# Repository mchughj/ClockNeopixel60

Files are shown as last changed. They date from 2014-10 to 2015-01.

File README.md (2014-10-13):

ClockNeopixel60
===============

An Arduino (ATTiny85 and ATmega328) clock project that uses a 60 neopixel ring.

This is the 60 pixel neopixel clock program written by Jason McHugh.  Feel free to drop me a line at mchughj@gmail.com for questions, comments, criticisms, concerns, etc.  :)  I've included here the sketches used as well as a Fritzing circuit diagram (both .fzz and .png forms).

The backstory.

I originally bought a 16 pixel neopixel ring, a trinket, and an RTC module:

- Trinket:        https://www.adafruit.com/product/1501
- 16 pixel ring:  https://www.adafruit.com/product/1463
- RTC DS1307:     https://www.adafruit.com/product/264

I used the 16 pixel ring in another project for my son Aidan (who went camping with his 6th grade class, so I created a 2 way mirror with the ring behind the mirror).  I saw the 60 pixel ring and decided to get one (well, actually 4):

- 60 pixel ring:  https://www.adafruit.com/product/1768

Squeezing a nicely animating LED clock into the 5,310 byte maximum of the trinket wasn't easy.  Just using the TimeWireM and TinyRTClib libraries used up 3,146 bytes of space.  This left just ~ 2k of space to do something neat.  I'm sure if I were writing the assembly and really thinking hard about how to do this then it wouldn't be too challenging.  But writing 'regular' C code made it non-trivial.  

I could have moved to an Arduino and not had to worry about the space but I wanted to challenge myself a bit and fit it on the ATTiny85.  

I wrote the follow after observing clocks and thinking about what I thought the ideal animation/behavior would be.

I use this program in two separate scenarios.  

1/  The first is using an 8mhz Trinket with a physical RTC module attached to it.  This was my final intended configuration but it left very little space for debugging problems.  

In this first mode you have to have installed the TinyWireM and TinyRTClib installed. 

- https://github.com/adafruit/TinyWireM
- https://github.com/adafruit/TinyRTCLib

2/  The second scenario in which this program can be used is using a bare Arduino.  No RTC is required in this configuration - the millis implementation is used.  This mode allowed me to debug lots of problems with my original implementation so you will see lots of Serial debugging output and the ability to set a specific time.  In this second mode you have to have installed the RTClib.
  https://github.com/adafruit/RTClib

These two modes of operation are just the specific builds that I have.  There is nothing magical about them and additional configurations can be achieved by changing the code below.  

To set the two modes you have to do two things:

1/  In the Arduino programming environment select either 'Uno' or 'Adafruit Trinket 8mhz'.  Based on this setting everything else should be derived.   (Remember to set the programmer to be "USBTinyISP" if you are using the trinket!   If  you see lots of errors with "not in sync" then this can be why.)

2/  Uncomment or comment out the Wire.h, RTClib.h, TinyWireM, and TinyRTClib.  This shouldn't be necessary but apparently the Arduino programming environment uses a simple scan of all #includes in order to know what libraries might be used.  The preprocessor and directives are not used which makes this, IMO, a bug.  So the workaround is to comment and uncomment.

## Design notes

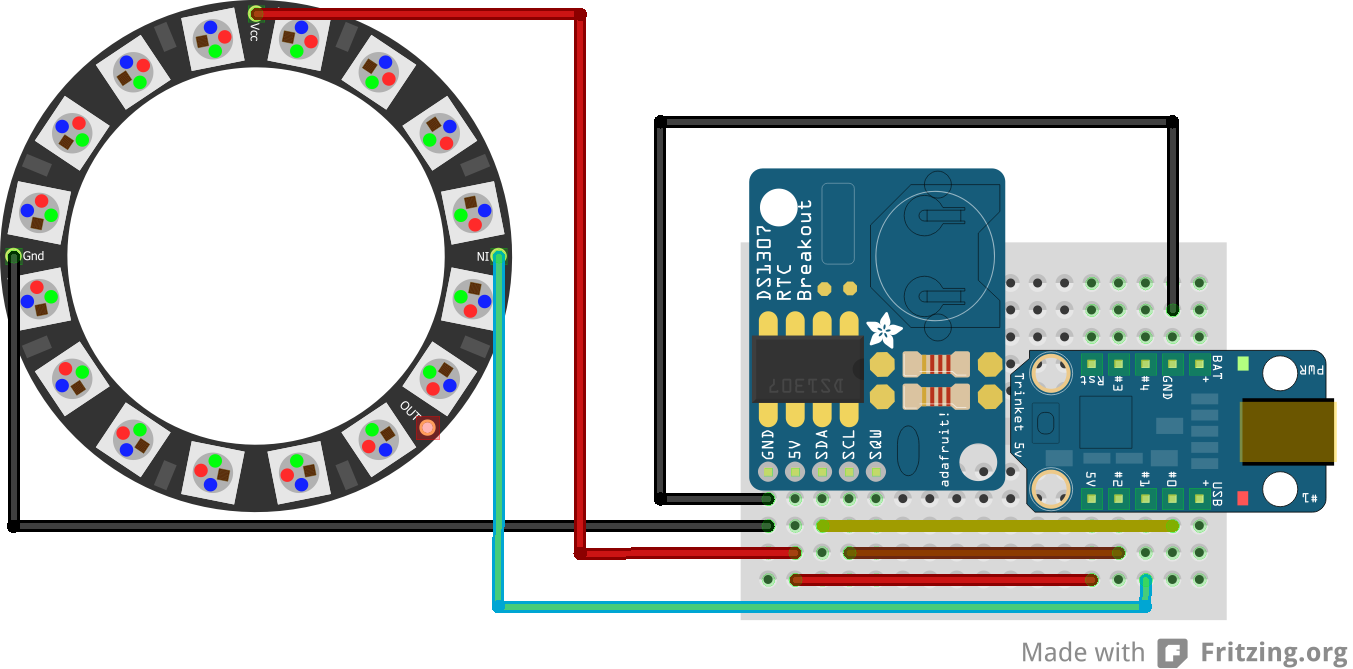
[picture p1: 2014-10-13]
Pixel-Ring-Trinket-Clock.png

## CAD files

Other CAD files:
Mom/DS1307AndArduinoProHolders.skp
Mom/ElectronicsEnclosure.skp

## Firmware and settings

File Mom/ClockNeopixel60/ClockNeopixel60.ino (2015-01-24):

/**
 * This is the 60 pixel neopixel clock program written by Jason McHugh.
 * 
 * This is a copy of my original program that I've forked and extended.  
 * In December 2014 my mother came to visit and remarked, several times!, 
 * how much she liked my clock.  I decided, with the prompting of a very
 * good friend, to make one for her.
 *
 * In making this version I decided to be smart this time in two 
 * significant ways.
 *
 * 1/  In the original version I challenged myself by putting the program
 * on a trinket - which has very limited memory space.  After putting on the
 * TinyWireM and TinyRTClib libraries I had only 3,146 bytes of programmer
 * space.  This time I'm using an Arduino Pro Mini with a full 8k of space.
 * This is huge and really makes the entire project easier.
 *
 * 2/  Day light savings time wasn't handled in my prior project so I'm adding
 * two buttons to support moving the hour and the minutes.  Minutes shouldn't 
 * be necessary but in case they want to synchronize with other clocks in the
 * house.
 * 
 * Project contents:
 *
 *   60 pixel ring:    https://www.adafruit.com/product/1768
 *   Arduino Pro Mini: https://www.sparkfun.com/products/11113
 *   RTC DS1307:       https://www.adafruit.com/product/264
 *   Pushbuttons:      https://www.adafruit.com/products/1009
 * 
 * End results: 
 * 
 *   1/  Interrupt service routines for buttons
 *   2/  Nicely animated clocks
 *   3/  Super happy Mom
 *
 * If you are interested in seeing a build of this project that works under
 * different settings then look around for the original Neopixel 60 clock
 * project.
 *
 * This project requires:
 *
 *   https://github.com/adafruit/RTClib
 *   https://github.com/adafruit/Adafruit_NeoPixel
 *
*/

// Use the serial libraries for debugging
#include <Serial>
#include <Wire.h>
#include <RTClib.h>
#define PIN 5

#include <Adafruit_NeoPixel.h>

// Uncomment out the following line to set the time.  Remember
// to reflash the same program with this commented out so that subsequent
// restarts don't reset the time.
// #define SET_TIME

// Uncomment out the following, but only when SET_TIME is defined,
// in order to test specific time values.
// #define USE_MANUAL_TEST_TIME

// Neopixel pin for the lights
#define NUMBER_PIXELS 60
#define BRIGHTNESS 128 // set max brightness

#define START_VALUE 0xfe

uint8_t hourTriggered = 0;
uint8_t minuteTriggered = 0;
uint32_t triggerTime;
uint8_t hourOffset = 0;
uint8_t minuteOffset = 0;

RTC_DS1307 rtc; // Clock object uses the real time clock module

Adafruit_NeoPixel strip = Adafruit_NeoPixel(NUMBER_PIXELS, PIN, NEO_GRB + NEO_KHZ800); // strip object

byte priorHourPixel = START_VALUE;
byte priorMinuteVal = START_VALUE;
byte priorSecondVal = START_VALUE;
boolean shownFifteen = false;

void setUniformRingColor( uint32_t color) {
    for(uint16_t i=0; i<NUMBER_PIXELS; i++) {
        strip.setPixelColor(i, color );
    }
}

void showOrientation() {
  Serial.println( "Going to show orientation" );
  setUniformRingColor(0);
  int numLeds = NUMBER_PIXELS;

  Serial.println( F("Top (Red): 0") );
  Serial.print( F("Right (Green): " ));
  Serial.println( (int) numLeds/4 );
  Serial.print( F("Bottom (Blue): " ));
  Serial.println( (int) numLeds/2 );
  Serial.print( F("Left (White): " ) );
  Serial.println( (int) numLeds/4*3 );
  
  for( int i = 0; i < 10; i++ ) {
      strip.setPixelColor(0, 0xff0000);
      strip.setPixelColor(numLeds/4, 0x00ff00);
      strip.setPixelColor(numLeds/2, 0x0000ff);
      strip.setPixelColor(numLeds/4*3, 0xffffff);
      strip.show();
      delay(150);
      setUniformRingColor(0);
      strip.show();
      delay(150);
  }
}

void setup () {
  strip.begin();
  strip.setBrightness(BRIGHTNESS); // set brightness
  
  Wire.begin();
  rtc.begin();

  Serial.begin(9600);
  Serial.println( F("Running Neopixel Clock 60 with serial debugging" ));
  Serial.print( F("Date: " ));
  Serial.print( __DATE__ );
  Serial.print( F(", Time: ") );
  Serial.println( __TIME__ );
  Serial.print( F("Initializing light pin to " ));
  Serial.println( PIN );
  showOrientation();

  if (! rtc.isrunning()) {
    Serial.println("RTC is NOT running!");
  }
   
#ifdef SET_TIME 
#ifdef USE_MANUAL_TEST_TIME
  const char *date = "Oct 12 2014";
  const char *time = "13:59:52";
#else
  const char *date = __DATE__;
  const char *time = __TIME__;;
#endif
 
  Serial.print( F("Going to manually set the RTC time to: "));
  Serial.print( date );
  Serial.print( F(" " ));
  Serial.println( time );
  rtc.adjust(DateTime( date, time ) );
#endif

  while(! rtc.isrunning()) {
    Serial.println("RTC is NOT running!");
  }
  
  // Enable interrupt 0 (pin 2) which is connected to a button
  // that controls the hour increment.
  attachInterrupt(0, incrementHour, RISING);

  // Enable interrupt 1 (pin 3) which is connected to a button
  // that controls the minute increment.
  attachInterrupt(1, incrementMinute, RISING);
}


/**
 * This routine will add a red, green, and blue color value to the current
 * color value for a pixel.  This creates a blend of the two colors. 
 *
 * The specific index for the pixel to be set can have a value -NUMBER_PIXELS
 * to NUMBER_PIXELS and it will be normalized into the range of 0 ->
 * NUMBER_PIXELS - 1.
 */
void addColorToPixel( int pixel, int red, int green, int blue ) { 
   if( pixel == NUMBER_PIXELS ) { 
     pixel = 0;
   } else if ( pixel < 0 ) { 
     pixel = NUMBER_PIXELS + pixel;
   }
   uint32_t currentPixelColor = strip.getPixelColor(pixel);
   
   int currentRed = (currentPixelColor & 0xFF0000) >> 16;
   int currentGreen = (currentPixelColor & 0x00FF00) >> 8;
   int currentBlue = currentPixelColor & 0x0000FF;
   
   strip.setPixelColor(pixel, currentRed + red, currentGreen + green, currentBlue + blue);
}

/**
 * Adds a color to a pixel, via addColorToPixel, and then does the same for
 * the surrounding pixels but at a reduced intensity.
 */
void addColorToPixelAndShadeAround( int pixel, uint8_t red, uint8_t green, uint8_t blue ) { 
    addColorToPixel( pixel, red, green, blue);
    red = red >> 4;
    green = green >> 4;
    blue = blue >> 4;
    
    addColorToPixel(pixel+1,red,green,blue);
    addColorToPixel(pixel-1,red,green,blue);
}

/**
 * Draw a single frame of a transition.  
 *
 * This method takes in the pixel that it will be animating, what the current
 * step of the animation is, the maximum number of steps, and finally the
 * color for the central pixel.  
 *
 * The animation frame will 'bleed' the color from the initial three pixels
 * into four pixels - the original three and the next pixel.
 */
void showTransitionStep( int pixel, int curTransitionStep, int maxTransitionSteps, int red, int green, int blue ) { 

   // The pixel that we are leaving
   addColorToPixel( pixel - 2, 
       red >> (4+curTransitionStep), 
       green >> (4+curTransitionStep), 
       blue >> (4+curTransitionStep) );

   // The pixel that used to be the brightest but now will be shaded dimly and
   // which preceeds the actual pixel for the time.
   addColorToPixel( pixel - 1, red >> curTransitionStep, green >> curTransitionStep, blue >> curTransitionStep );

   // The pixel that will now be the brightest and center.
   addColorToPixel( pixel, red >> (4-curTransitionStep), green >> (4-curTransitionStep), blue >> (4-curTransitionStep) );

   // Finally the pixel that follows the brightest which will become shaded
   // and bright as the transition nears the max steps.
   addColorToPixel( pixel+1, 
       red >> ( 4 + maxTransitionSteps - curTransitionStep), 
       green >> ( 4 + maxTransitionSteps - curTransitionStep), 
       blue >> ( 4 + maxTransitionSteps - curTransitionStep) );
}


/**
 * Show the transition from one time to the next.
 */
void transition( int hourVal, byte minuteVal, byte secondVal ) { 
  uint8_t amount = 0xff;
  int time = 200;
  int maximumTransitions = 4;
  int hourPixel = map( hourVal, 0, 719, 0, 59 );

  for( int i = 0; i <= maximumTransitions; i++ ) { 
       setUniformRingColor(0);
       
       if( priorHourPixel != hourPixel ) { 
         showTransitionStep( hourPixel, i, maximumTransitions, 0xff, 0, 0 );
       } else {
         addColorToPixelAndShadeAround( hourPixel, 0xff, 0, 0 );
       }
       
       if( priorMinuteVal != minuteVal ) { 
         showTransitionStep( minuteVal, i, maximumTransitions, 0, 0xff, 0 );
       } else {
         addColorToPixelAndShadeAround( minuteVal, 0, 0xff, 0 );
       }
       showTransitionStep( secondVal, i, maximumTransitions, 0, 0, 0xff);
       
       strip.show();
       delay(time);
  }
  priorHourPixel = hourPixel;
}

uint32_t Wheel(byte WheelPos) {
  if(WheelPos < 85) {
   return strip.Color(WheelPos * 3, 255 - WheelPos * 3, 0);
  } else if(WheelPos < 170) {
   WheelPos -= 85;
   return strip.Color(255 - WheelPos * 3, 0, WheelPos * 3);
  } else {
   WheelPos -= 170;
   return strip.Color(0, WheelPos * 3, 255 - WheelPos * 3);
  }
}

void showColorWheel() {
  uint16_t i, j;

  // Turn down the brightness to be safe.  There are 60 pixels and at full brightness and with
  // all white then each would be about 60 milliamps.  This is 3.6 amps total.  I'm using a 2
  // amp power supply.  I've set the default BRIGHTNESS to be a safe value even with all white
  // but here I'm going to decrease it just a bit to be extra safe.
  strip.setBrightness(BRIGHTNESS*0.85);
  for(j=256*4; j>0; j--) { 
    for(i=0; i< strip.numPixels(); i++) {
      strip.setPixelColor(i, Wheel(((i * 256 / strip.numPixels()) + j) & 255));
    }
    strip.show();
    delay(3);
  }
  strip.setBrightness(BRIGHTNESS);
}

void showFifteenMinuteIncrements(byte minuteVal) {
  uint32_t color;
  if( minuteVal == 0 ) { 
    
    showColorWheel();
    return;
  } else if( minuteVal == 15 ) { 
    color = 0x00ff00;
  } else if( minuteVal == 30 ) { 
    color = 0xff0000;
  } else if( minuteVal == 45 ) { 
    color = 0x0000ff;
  } else {
    color = 0xff00ff;
  }
  for( int i = 0; i < 5; i++ ) { 
        setUniformRingColor( color );
        strip.show();
        delay(300);
        setUniformRingColor( 0x0 );
        strip.show();
        delay(300);
    }
}

void loop() 
{
  uint32_t currentTime = millis();
  
  // Look to see if the interrupt routines registered a button press.  
  // If so then acknowledge the trigger and, if it is the first pass
  // through this main loop since it has been triggered, run the routine
  // to process the button press.
  if( hourTriggered == 1 ) { 
    hourTriggered = 0;
    Serial.println( "Hour triggered" );
    if (triggerTime == 0) {
      Serial.println( "Incrementing hour offset" );
      triggerTime = currentTime;
      incrementHourOffset();
    }
  }
  if( minuteTriggered == 1 ) { 
    minuteTriggered = 0;
    Serial.println( "Minute triggered" );
    if (triggerTime == 0) {
      Serial.println( "Incrementing minute" );
      triggerTime = currentTime;
      incrementMinuteOffset();
    }
  }
  
  // Handle a uint32_t wrapping around every couple of days or so.
  if( triggerTime + 750 < triggerTime ) { 
    triggerTime = 0;
  }  
  
  // After some amount of times has passed allow another trigger event to occur.
  if( triggerTime != 0 && currentTime > triggerTime + 750 ) { 
    triggerTime = 0;
  }
  
  // Get the current time
  DateTime n = rtc.now(); 

  byte secondVal = n.second();  
  byte minuteVal = n.minute();  
 
  // Since hour granularity is too coarse - we have 60 pixels and there are
  // only 12 hour values - we translate the raw hour value into an hourVal
  // which is the number of minutes that have elapsed within the 12 hour
  // period.  This gives us a range from 0 to 719 which can be mapped to the
  // ring's 60 pixels nicely.
  byte hour = n.hour();
  hour += hourOffset;
  while( hour >= 12 ) { 
    hour -= 12;
  }
  
  minuteVal += minuteOffset;
  if( minuteVal > 60 ) { 
    minuteVal -= 60;
  }
  
  uint16_t hourVal = ((uint16_t)hour) * 60 + ( uint16_t) minuteVal;
  
  Serial.print( "currentHour: " );
  Serial.print( hour );
  Serial.print( ", hourVal: " );
  Serial.print( hourVal );
  Serial.print( ", currentMinute: " );
  Serial.print( minuteVal );
  Serial.print( ", currentSecond: " );
  Serial.println( secondVal );
  
  if( priorSecondVal == secondVal ) { 
      return;
  }   
  
  transition( hourVal, minuteVal, secondVal );
  
  priorMinuteVal = minuteVal;
  priorSecondVal = secondVal;

  // Every fifteen minutes do a little something obvious to indicate that
  // time has passed.
  if(( minuteVal == 0 || minuteVal == 15 || minuteVal == 30 || minuteVal == 45 ) ) {
    if( shownFifteen == false ) { 
       showFifteenMinuteIncrements( minuteVal );
       shownFifteen = true;
    }
  } else { 
    shownFifteen = false;
  }
}

// ISR for hour button
void incrementHour() {
  hourTriggered = 1;
}

void incrementHourOffset() {
    hourOffset++;
    if( hourOffset == 24 ) { 
       hourOffset = 0;
    }
}


// ISR for minute button
void incrementMinute() {
  minuteTriggered = 1;
}

void incrementMinuteOffset() {
    minuteOffset++;
    if( minuteOffset == 60 ) { 
       minuteOffset = 0;
    }
}

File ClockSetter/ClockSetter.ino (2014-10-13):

/**
 * Use this program to set the time of the clock in your RTC DS1307 to the
 * current time of the machine compiling and pushing the sketch.  This is
 * necessary, usually just once, when you put together your RTC.
 */

#include <TinyWireM.h>
#include <TinyRTClib.h>

RTC_DS1307 rtc;

#ifdef __AVR_ATtiny85__
// Trinket has an led on pin 1
#define PIN 1
#else
// Arduino boards typically have an led on pin 13.
#define PIN 13
#endif


void setup()
{
  // Begin I2C
  TinyWireM.begin();
  rtc.begin();
  rtc.adjust(DateTime(__DATE__, __TIME__));

  pinMode(PIN,OUTPUT);
  for(uint8_t i=0; i<10; i++) {
      digitalWrite(PIN, HIGH);
      delay(500);
      digitalWrite(PIN, LOW);
      delay(500);
  }
}

void loop() { }

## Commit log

2014-10-13 Added circuit diagram and initialization sketch
    [Pixel-Ring-Trinket-Clock.fzz]
2015-01-24 Version of the project for my Mother
    [DS1307AndArduinoProHolders.skp, ElectronicsEnclosure.skp]
